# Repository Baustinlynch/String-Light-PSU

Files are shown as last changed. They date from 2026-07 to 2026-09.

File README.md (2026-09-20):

# String-light-controller

an esp-home controller for 4.5V string-lights with PWM dimming and a battery with USB-C recharging.
comes in a version with an 18650 battery holder and a version with a JST PH connector. The JST version is more compact

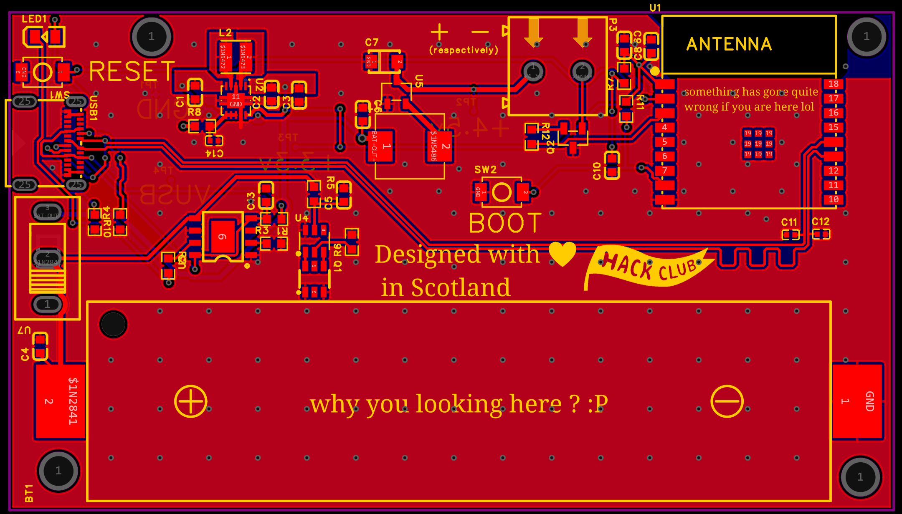
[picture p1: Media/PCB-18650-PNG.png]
an image of the 18650 version of the board's PCB


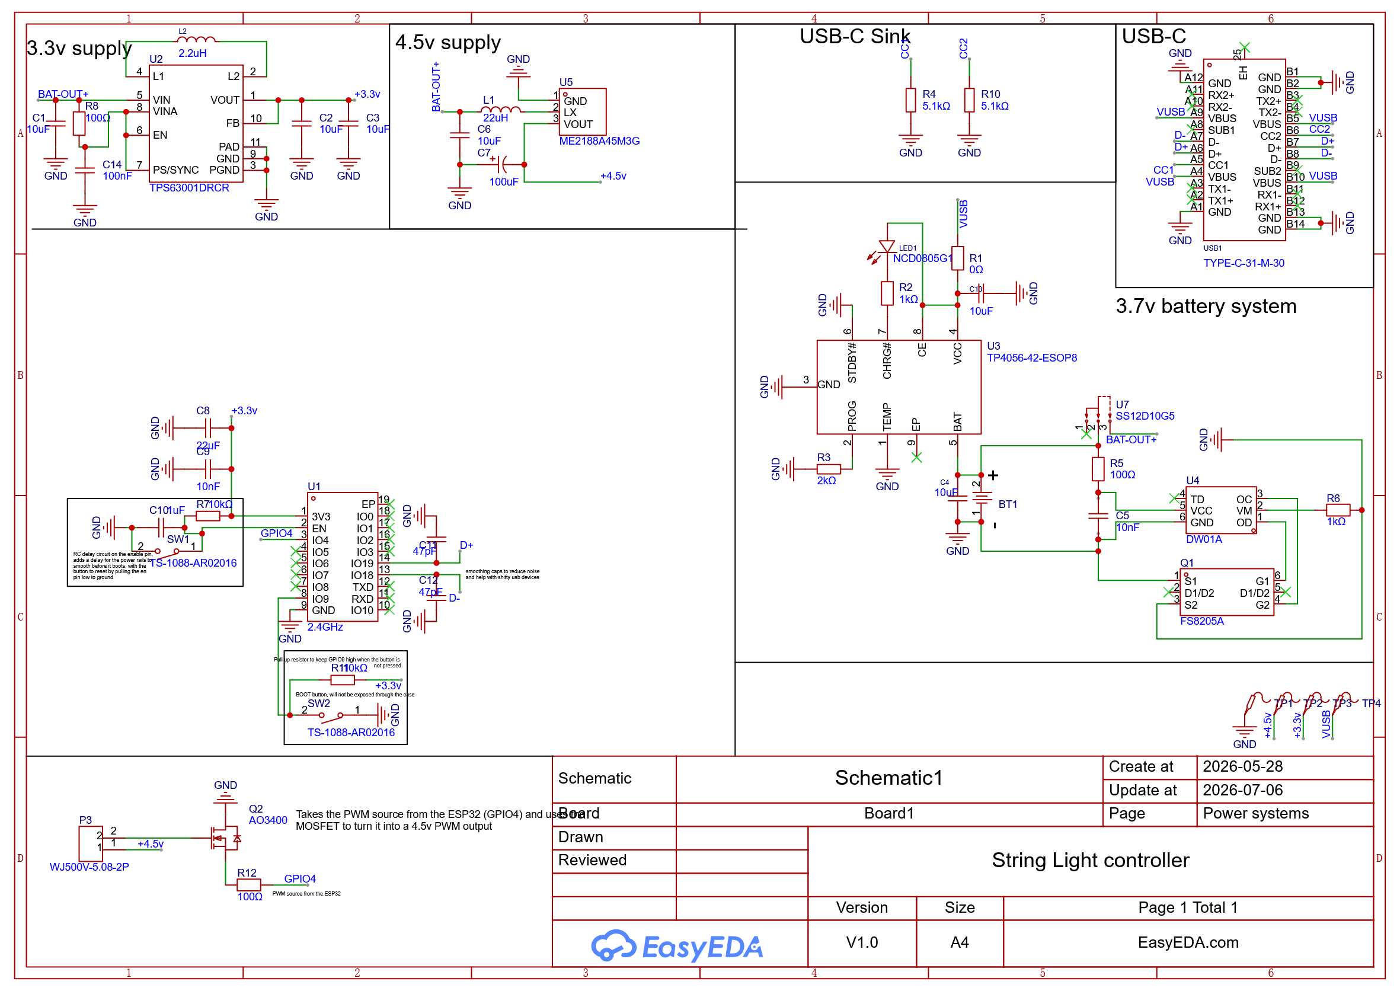
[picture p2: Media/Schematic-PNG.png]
an image of the 18650 version of the board's schematic


## ESP-home implementation

the lights can be controlled using the ESP-home "component" [ESP-32 LEDC output](https://esphome.io/components/output/ledc/).
it allows for the easy creation of a HomeAssistant light entity with dimming based on the PWM output of the esp32 through basic yaml configuration files, that automatically generate the code needed to flash the ESP32, and allow you to flash it through ESP-home web tools.
to define a light using this component, all you **need** to declare in your ESP-home config is the pin on the esp32 (in the case of this board, GPIO4) and the ID that you want the light component to have in HomeAssistant. You can also set the PWM frequency of the pin, the ESP32-C3 which is used in this board only supports 14 bit LEDC timers, as shown on the frequency table on the ESP-home docs page i linked.
Here is an example configuation:

``` yaml
# Example configuration entry
output:
  - platform: ledc
    pin: GPIOXX
    id: gpio_

# Example usage in a light
light:
  - platform: monochromatic
    output: gpio_19
    name: "Kitchen Light"
```

## Operation

The board features an ESP32-C3 to interface with the PWM pin at GPIO4, which is then transformed through the MOSFET (Q2) into a 4.5v PWM signal.
The PWM output can be used to change the brightness of the lights, and can be easily controled through esp-home to turn any 4.5v string lights into smart-lights with HomeAssistant!
String lights that use 3 AA or AAA batteries often operate at 4.5v and should be compatible with this board.
When charging, the red LED (LED1) located next to the usb-c port will be on. it will turn off when full charged

## Assembly
[go to assembly](Assembly.md)

# BATTERY DISCLAIMER !!!
LiPo and LiIon batteries are **pretty dangerous**!! 
I **DO NOT** take responsibility for my battery charging or management circuitry being responsible for your battery being over/under charged and setting on fire.
I trust my circuitry enough to use it in my own home, but you should always look over someone else's circuitry yourself and do your due diligence!
**Use at your own risk!!**

## AI Declaration
Coding and research agents were used in this project, for things like the preparation of the spreadsheets, and for finding blatant errors in my schematics that I may have missed.

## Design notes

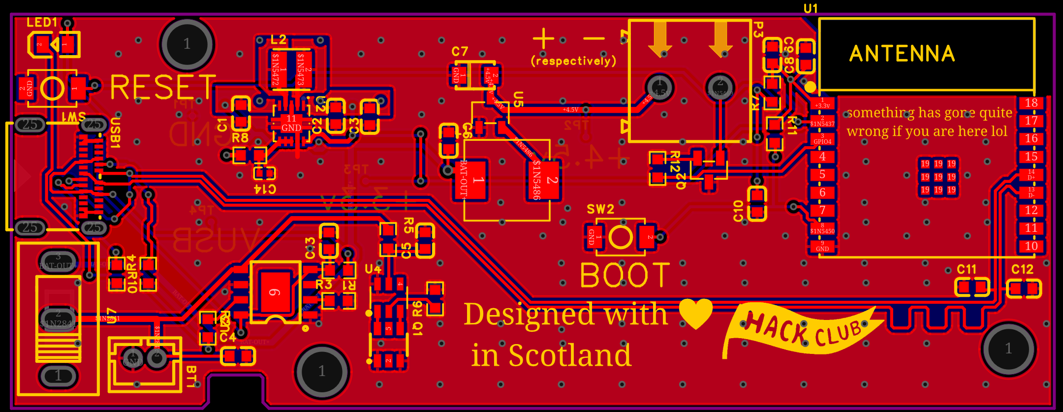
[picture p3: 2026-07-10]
Media/PCB-JST-PNG.png

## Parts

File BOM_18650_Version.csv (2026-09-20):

Part | Quantity | Price | Total
BH-18650-B1BA002 | 1 | 2.0 | 2.0
10uF (C96446) | 4 | 0.0549 | 0.2196
10uF (C96446) | 2 | 0.0549 | 0.1098
10nF (C5137477) | 2 | 0.0072 | 0.0144
100uF (C561794) | 1 | 0.4221 | 0.4221
22uF (C86295) | 1 | 0.0434 | 0.0434
1uF (C15849) | 1 | 0.0153 | 0.0153
47pF (C1671) | 2 | 0.0064 | 0.0128
100nF (C525226) | 1 | 0.0052 | 0.0052
22uH (C128694) | 1 | 0.0846 | 0.0846
2.2uH (C668451) | 1 | 0.1696 | 0.1696
NCD0805G1 | 1 | 2.0 | 2.0
WJ500V-5.08-2P | 1 | 2.0 | 2.0
FS8205A | 1 | 2.0 | 2.0
AO3400 | 1 | 2.0 | 2.0
0Ω (C844915) | 1 | 0.0035 | 0.0035
1kΩ (C2907002) | 2 | 0.0029 | 0.0058
2kΩ (C22975) | 1 | 0.0024 | 0.0024
5.1kΩ (C23186) | 2 | 0.0018 | 0.0036
100Ω (C2906981) | 3 | 0.0021 | 0.0063
10kΩ (C98220) | 2 | 0.0035 | 0.0070
TS-1088-AR02016 | 2 | 2.0 | 4.0
Test-Point | 4 | 2.0 | 8.0
2.4GHz (C2934560) | 1 | 3.3224 | 3.3224
TPS63001DRCR | 1 | 2.0 | 2.0
TP4056-42-ESOP8 | 1 | 2.0 | 2.0
DW01A | 1 | 2.0 | 2.0
ME2188A45M3G | 1 | 2.0 | 2.0
SS12D10G5 | 1 | 2.0 | 2.0
TYPE-C-31-M-30 | 1 | 2.0 | 2.0
3D Printed Case (Base & Top) | 1 | 1.0 | 1.0
M3 x 5mm Threaded Inserts | 4 | 0.2 | 0.8
M3 x 8mm Machine Screws | 4 | 0.1 | 0.4
18650 Battery | 1 | 5.0 | 5.0
GRAND TOTAL | 1 | 73.2 | 73.2

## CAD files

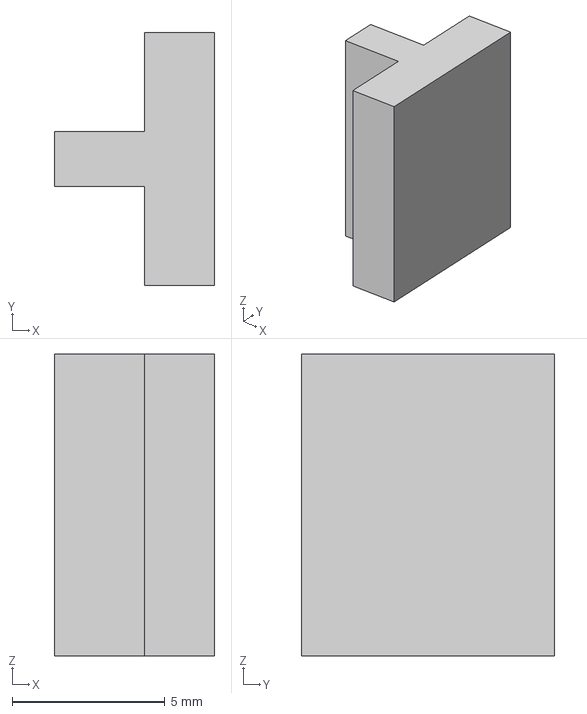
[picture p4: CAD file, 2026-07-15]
CAD/18650/Case Parts/Button Pin.step
5.25 x 8.30 x 9.89 mm

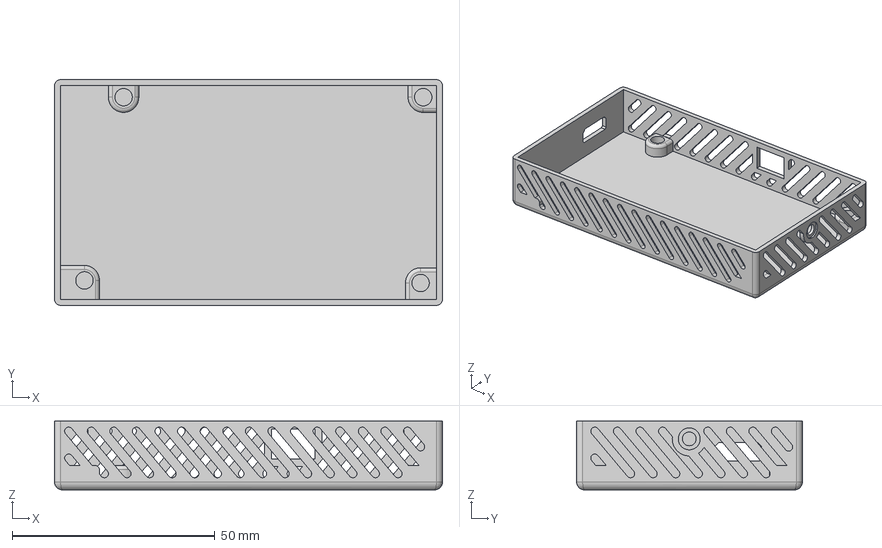
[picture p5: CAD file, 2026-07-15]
CAD/18650/Case Parts/Base.step
95.7 x 55.7 x 17.0 mm

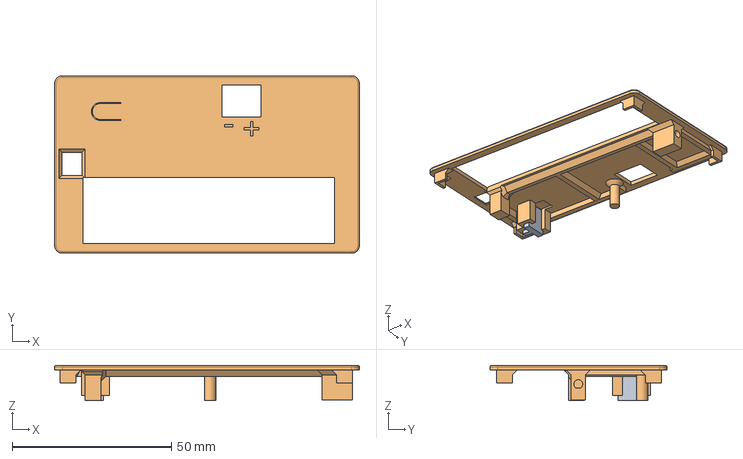
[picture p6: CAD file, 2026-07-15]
CAD/18650/Case Parts/Top.step
95.7 x 55.7 x 11.1 mm

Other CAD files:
CAD/18650/Case Parts/Base.f3d
CAD/18650/Case Parts/Button Pin.f3d
CAD/18650/Case Parts/Top.f3z

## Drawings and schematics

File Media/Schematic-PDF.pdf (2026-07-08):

GND B14 GND B13 RX1+ B12 RX1- B11 VBUS B10 SUB2 B9 D- B8 D+ B7 CC2 B6 VBUS B5 TX2- B4 TX2+ B3 GND B2 GND B1

USB-C Sink | USB-C

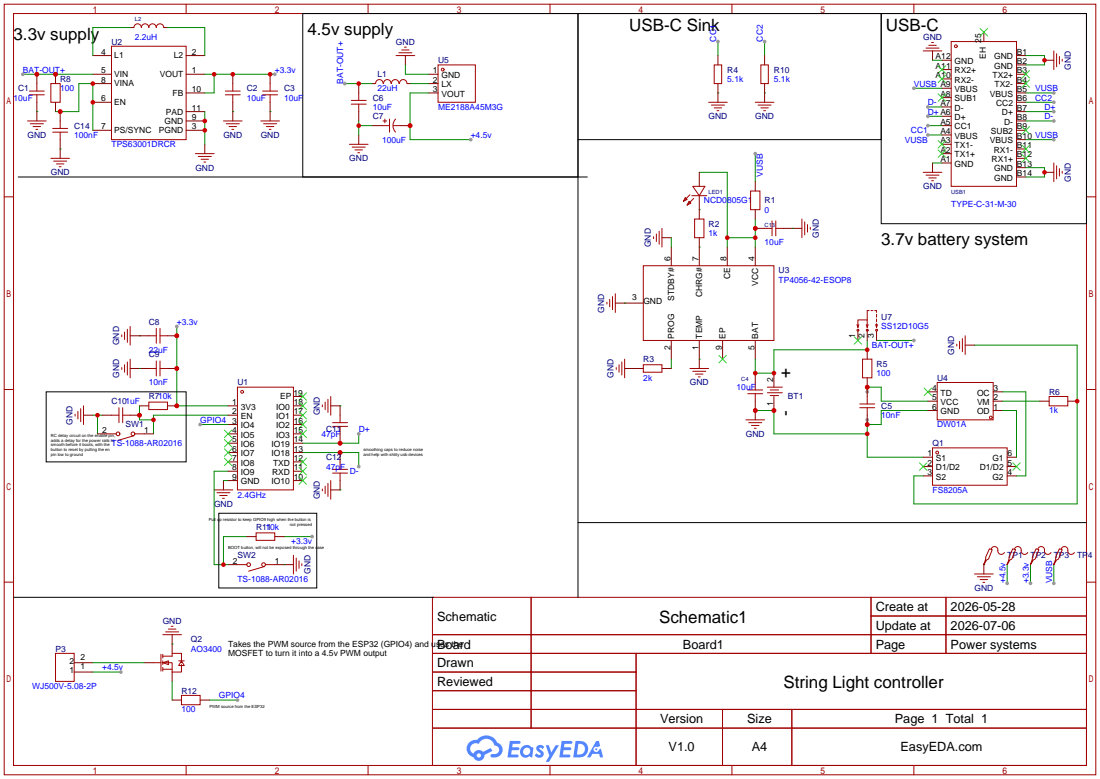
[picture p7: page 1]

RC delay circuit on the enable pin,
adds a delay for the power rails to
smooth before it boots, with the
button to reset by pulling the en
pin low to ground

smoothing caps to reduce noise
and help with shitty usb devices

Pull up resistor to keep GPIO9 high when the button is

BOOT button, will not be exposed through the case

Update at | 2026-07-06

Board | Board1 | Page | Power systems
Drawn | | String Light controller
Reviewed

Takes the PWM source from the ESP32 (GPIO4) and uses the
MOSFET to turn it into a 4.5v PWM output

PWM source from the ESP32

Version | Size | Page 1 Total 1
V1.0 | A4 | EasyEDA.com

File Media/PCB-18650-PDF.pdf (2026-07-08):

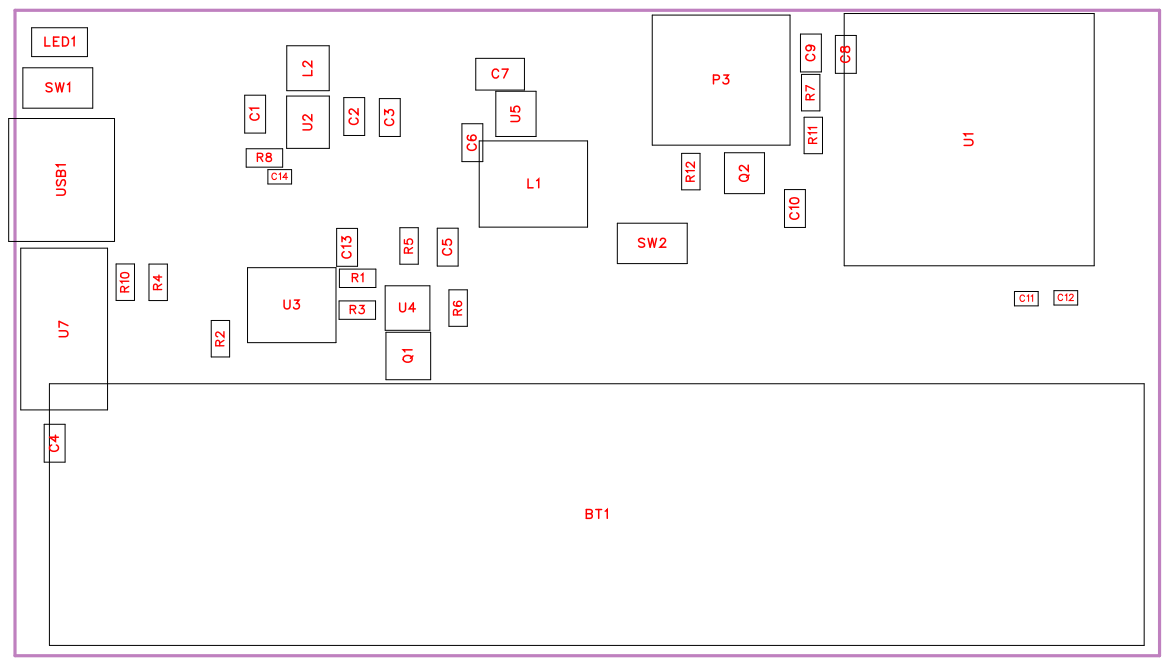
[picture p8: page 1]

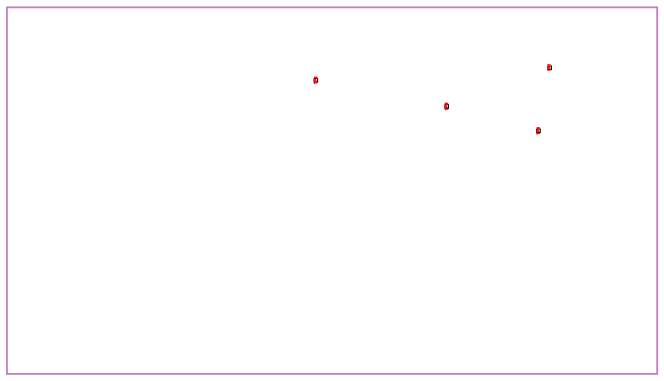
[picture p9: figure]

No. | Quantity | Comment | Designator | Footprint | Value | Manufacturer Part | Manufacturer | Supplier Part | Supplier
1 | 1 | BH-18650-B1 BA002 | BT1 | BATTERY-S MD_18650-1 S-L77.1-W20 .7-1 | | BH-18650-B1 BA002 | MYOUNG( 美 ) 阳 | C2988620 | LCSC
2 | 4 | 10uF | C1,C2,C3,C6 | C0603 | 10uF | CL10B106M Q8NRNC | SAMSUNG( ) 三星 | C3039698 | LCSC
3 | 2 | 10uF | C4,C13 | C0603 | 10uF | CL10A106M A8NRNC | SAMSUNG( ) 三星 | C96446 | LCSC
4 | 2 | 10nF | C5,C9 | C0603 | 10nF | FCC0603B10 3K500CT | FOJAN(富捷 ) | C5137477 | LCSC
5 | 1 | 100uF | C7 | CAP-SMD_L 3.2-W1.6 | 100uF | T520A107M0 06ATE070 | KEMET(基美 ) | C561794 | LCSC
6 | 1 | 22uF | C8 | C0603 | 22uF | CL10A226M P8NUNE | SAMSUNG( 三星 ) | C86295 | LCSC
7 | 1 | 1uF | C10 | C0603 | 1uF | CL10A105KB 8NNNC | SAMSUNG( ) 三星 | C15849 | LCSC
8 | 2 | 47pF | C11,C12 | C0402 | 47pF | CC0402FRN PO9BN470 | YAGEO(国巨 ) | C277503 | LCSC
9 | 1 | 100nF | C14 | C0402 | 100nF | FN15X104K5 00PKG | PSA(信昌电 陶) | C525226 | LCSC
10 | 1 | 22uH | L1 | IND-SMD_L7 .3-W6.6_MH CI06030 | 22uH | SMMS0630-220M | SXN(顺翔诺 ) | C128694 | LCSC
11 | 1 | 2.2uH | L2 | IND-SMD_L3 .0-W3.0_LQ H3NPN2R2N G0L | 2.2uH | LQH3NPN2R 2MMEL | muRata(村田 ) | C668451 | LCSC
12 | 1 | NCD0805G1 | LED1 | LED0805-R-RD | | NCD0805G1 | 国星光电 | C84260 | LCSC
13 | 1 | WJ500V-5.08 -2P | P3 | CONN-TH_2 P-P5.00_WJ 500V-5.08-2 P | | WJ500V-5.08 -2P | KANGNEX( 康奈克斯电气 ) | C8465 | LCSC
14 | 1 | FS8205A | Q1 | SOT-23-6_L2 .9-W1.6-P0.9 5-LS2.8-BR | | FS8205A | TECH PUBLI C(台舟 ) | C2830320 | LCSC
15 | 1 | AO3400 | Q2 | SOT-23-3_L2 .9-W1.3-P0.9 5-LS2.4-BR | | AO3400 | ElecSuper( 静 芯 ) | C5224189 | LCSC
16 | 1 | 0 | R1 | R0603 | 0 | CRCW06030 000Z0EA | VISHAY(威世 ) | C844915 | LCSC
17 | 2 | 1k | R2,R6 | R0603 | 1k | FRC0603F10 01TS | FOJAN(富捷 ) | C2907002 | LCSC
18 | 1 | 2k | R3 | R0603 | 2k | 0603WAF20 01T5E | UNI-ROYAL( ) 厚声 | C22975 | LCSC
19 | 2 | 5.1k | R4,R10 | R0603 | 5.1k | 0603WAF51 01T5E | UNI-ROYAL( 厚声 ) | C23186 | LCSC

20 | 3 | 100 | R5,R8,R12 | R0603 | 100 | FRC0603F10 00TS | FOJAN(富捷 ) | C2906981 | LCSC
21 | 2 | 10k | R7,R11 | R0603 | 10k | RC0603FR-0 710KL | YAGEO(国巨 ) | C98220 | LCSC
22 | 2 | TS-1088-AR 02016 | SW1,SW2 | SW-SMD_L3 .9-W3.0-P4.4 5 | | TS-1088-AR 02016 | XUNPU(讯普 ) | C720477 | LCSC
23 | 4 | Test-Point | TP1,TP2,TP3,TP4 | Test-Point-0. 5mm
24 | 1 | 2.4GHz | U1 | BULETM-SM D_ESPRESS IF_ESP32-C 3-WROOM-0 2-N4-4MB | 2.4GHz | ESP32-C3-W ROOM-02-N 4 | ESPRESSIF( 乐鑫 ) | C2934560 | LCSC
25 | 1 | TPS63001D RCR | U2 | VSON-10_L3 .0-W3.0-P0.5 0-TL-EP_TP S62410DRC R | | TPS63001D RCR | TI(德州仪器 ) | C28060 | LCSC
26 | 1 | TP4056-42-E SOP8 | U3 | ESOP-8_L4. 9-W3.9-P1.2 7-LS6.0-BL-E P | | TP4056-42-E SOP8 | TOPPOWER (南京拓微) | C16581 | LCSC
27 | 1 | DW01A | U4 | SOT-23-6_L2 .9-W1.6-P0.9 5-LS2.8-BL | | DW01A | PUOLOP( 迪 ) 浦 | C351410 | LCSC
28 | 1 | ME2188A45 M3G | U5 | SOT-23-3_L2 .9-W1.6-P1.9 0-LS2.8-BR | | ME2188A45 M3G | MICRONE( 南 ) 京微盟 | C2835781 | LCSC
29 | 1 | SS12D10G5 | U7 | SW-TH_SHO U-HAN_SS1 2D10G4 | | SS12D10G5 | SHOU HAN(首韩 ) | C7431054 | LCSC
30 | 1 | TYPE-C-31-M-30 | USB1 | USB-C-SMD _TYPE-C-31-M-30 | | TYPE-C-31-M-30 | 韩国韩荣 | C2689970 | LCSC

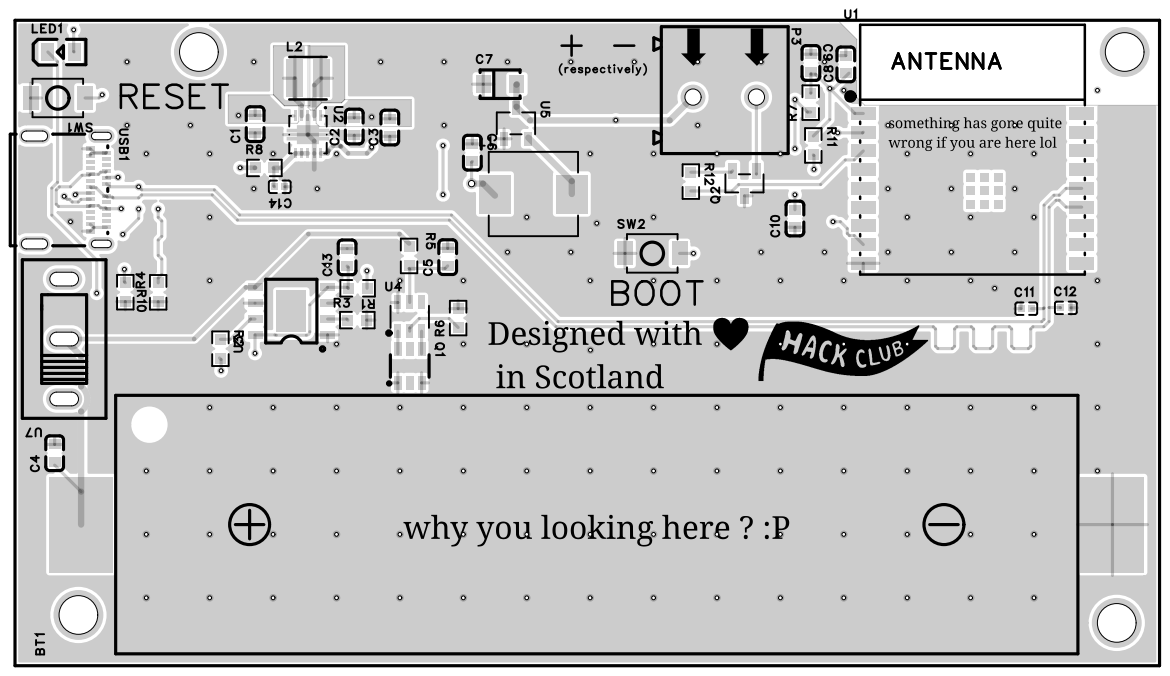
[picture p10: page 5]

LED1 | ANTENNA

something has gone quite
wrong if you are here lol

why you looking here ? :P

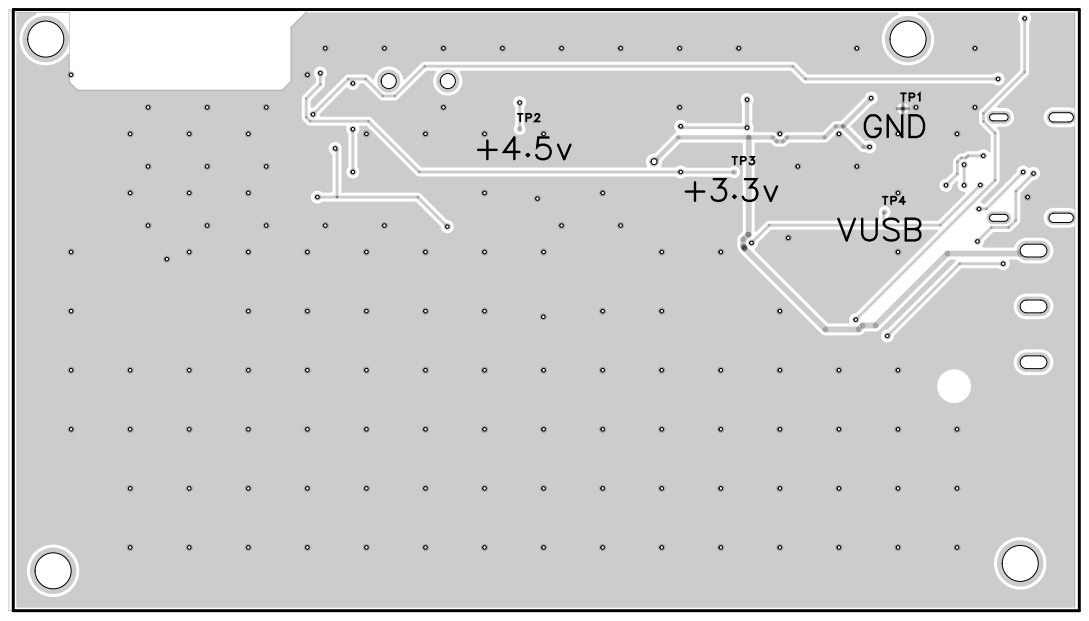
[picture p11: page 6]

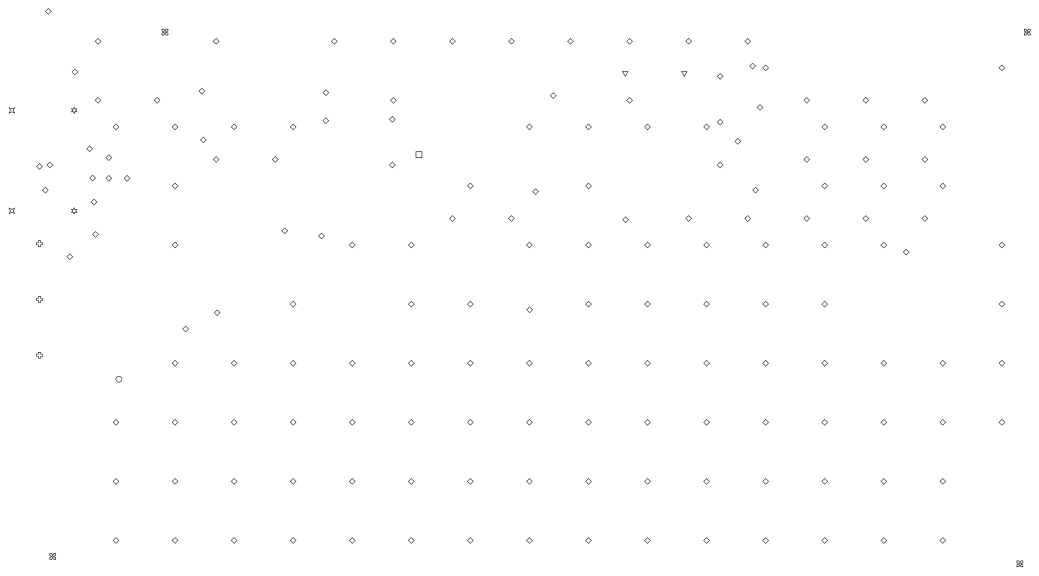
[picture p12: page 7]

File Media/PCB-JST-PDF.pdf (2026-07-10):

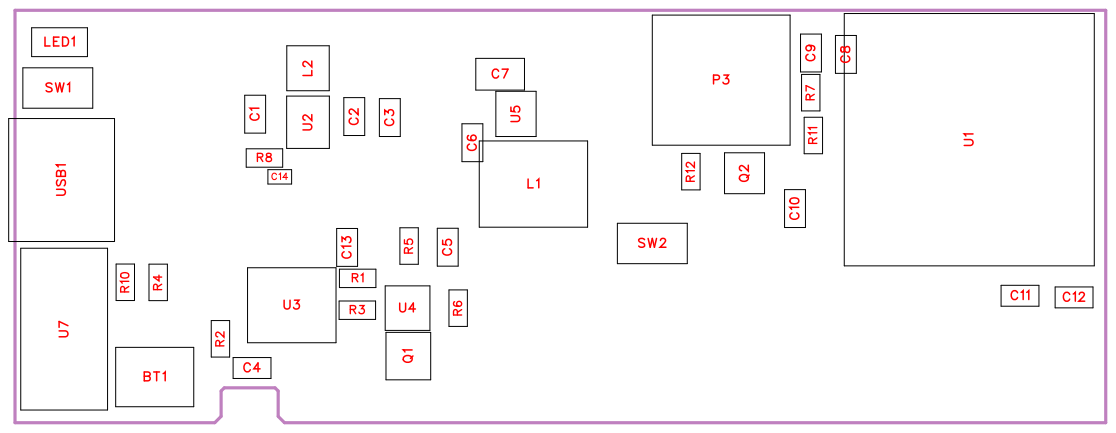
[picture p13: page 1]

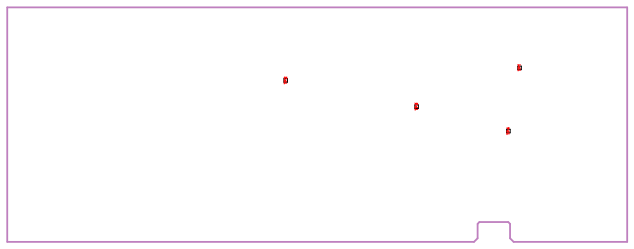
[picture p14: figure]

No. | Quantity | Comment | Designator | Footprint | Value | Manufacturer Part | Manufacturer | Supplier Part | Supplier
1 | 1 | B2B-PH-K-S( LF)(SN) | BT1 | CONN-TH_B 2B-PH-K-S | | B2B-PH-K-S( LF)(SN) | JST | C131337 | LCSC
2 | 4 | 10uF | C1,C2,C3,C6 | C0603 | 10uF | CL10B106M Q8NRNC | SAMSUNG( ) 三星 | C3039698 | LCSC
3 | 2 | 10uF | C4,C13 | C0603 | 10uF | CL10A106M A8NRNC | SAMSUNG( 三星 ) | C96446 | LCSC
4 | 2 | 10nF | C5,C9 | C0603 | 10nF | FCC0603B10 3K500CT | FOJAN(富捷 ) | C5137477 | LCSC
5 | 1 | 100uF | C7 | CAP-SMD_L 3.2-W1.6 | 100uF | T520A107M0 06ATE070 | KEMET(基美 ) | C561794 | LCSC
6 | 1 | 22uF | C8 | C0603 | 22uF | CL10A226M P8NUNE | SAMSUNG( ) 三星 | C86295 | LCSC
7 | 1 | 1uF | C10 | C0603 | 1uF | CL10A105KB 8NNNC | SAMSUNG( ) 三星 | C15849 | LCSC
8 | 2 | 47pF | C11,C12 | C0603 | 47pF | CL10C470JB 8NNNC | SAMSUNG( 三星 ) | C1671 | LCSC
9 | 1 | 100nF | C14 | C0402 | 100nF | FN15X104K5 00PKG | PSA(信昌电 陶) | C525226 | LCSC
10 | 1 | 22uH | L1 | IND-SMD_L7 .3-W6.6_MH CI06030 | 22uH | SMMS0630-220M | SXN(顺翔诺 ) | C128694 | LCSC
11 | 1 | 2.2uH | L2 | IND-SMD_L3 .0-W3.0_LQ H3NPN2R2N G0L | 2.2uH | LQH3NPN2R 2MMEL | muRata(村田 ) | C668451 | LCSC
12 | 1 | NCD0805G1 | LED1 | LED0805-R-RD | | NCD0805G1 | 国星光电 | C84260 | LCSC
13 | 1 | WJ500V-5.08 -2P | P3 | CONN-TH_2 P-P5.00_WJ 500V-5.08-2 P | | WJ500V-5.08 -2P | KANGNEX( 康奈克斯电气 ) | C8465 | LCSC
14 | 1 | FS8205A | Q1 | SOT-23-6_L2 .9-W1.6-P0.9 5-LS2.8-BR | | FS8205A | TECH PUBLI C(台舟 ) | C2830320 | LCSC
15 | 1 | AO3400 | Q2 | SOT-23-3_L2 .9-W1.3-P0.9 5-LS2.4-BR | | AO3400 | ElecSuper( 静 ) 芯 | C5224189 | LCSC
16 | 1 | 0 | R1 | R0603 | 0 | CRCW06030 000Z0EA | VISHAY(威世 ) | C844915 | LCSC
17 | 2 | 1k | R2,R6 | R0603 | 1k | FRC0603F10 01TS | FOJAN(富捷 ) | C2907002 | LCSC
18 | 1 | 2k | R3 | R0603 | 2k | 0603WAF20 01T5E | UNI-ROYAL( 厚声 ) | C22975 | LCSC
19 | 2 | 5.1k | R4,R10 | R0603 | 5.1k | 0603WAF51 01T5E | UNI-ROYAL( 厚声 ) | C23186 | LCSC
20 | 3 | 100 | R5,R8,R12 | R0603 | 100 | FRC0603F10 00TS | FOJAN(富捷 ) | C2906981 | LCSC

21 | 2 | 10k | R7,R11 | R0603 | 10k | RC0603FR-0 710KL | YAGEO(国巨 ) | C98220 | LCSC
22 | 2 | TS-1088-AR 02016 | SW1,SW2 | SW-SMD_L3 .9-W3.0-P4.4 5 | | TS-1088-AR 02016 | XUNPU(讯普 ) | C720477 | LCSC
23 | 4 | Test-Point | TP1,TP2,TP3,TP4 | Test-Point-0. 5mm
24 | 1 | 2.4GHz | U1 | BULETM-SM D_ESPRESS IF_ESP32-C 3-WROOM-0 2-N4-4MB | 2.4GHz | ESP32-C3-W ROOM-02-N 4 | ESPRESSIF( ) 乐鑫 | C2934560 | LCSC
25 | 1 | TPS63001D RCR | U2 | VSON-10_L3 .0-W3.0-P0.5 0-TL-EP_TP S62410DRC R | | TPS63001D RCR | TI(德州仪器 ) | C28060 | LCSC
26 | 1 | TP4056-42-E SOP8 | U3 | ESOP-8_L4. 9-W3.9-P1.2 7-LS6.0-BL-E P | | TP4056-42-E SOP8 | TOPPOWER (南京拓微) | C16581 | LCSC
27 | 1 | DW01A | U4 | SOT-23-6_L2 .9-W1.6-P0.9 5-LS2.8-BL | | DW01A | PUOLOP( 迪 浦 ) | C351410 | LCSC
28 | 1 | ME2188A45 M3G | U5 | SOT-23-3_L2 .9-W1.6-P1.9 0-LS2.8-BR | | ME2188A45 M3G | MICRONE( 南 ) 京微盟 | C2835781 | LCSC
29 | 1 | SS12D10G5 | U7 | SW-TH_SHO U-HAN_SS1 2D10G4 | | SS12D10G5 | SHOU HAN(首韩 ) | C7431054 | LCSC
30 | 1 | TYPE-C-31-M-30 | USB1 | USB-C-SMD _TYPE-C-31-M-30 | | TYPE-C-31-M-30 | 韩国韩荣 | C2689970 | LCSC

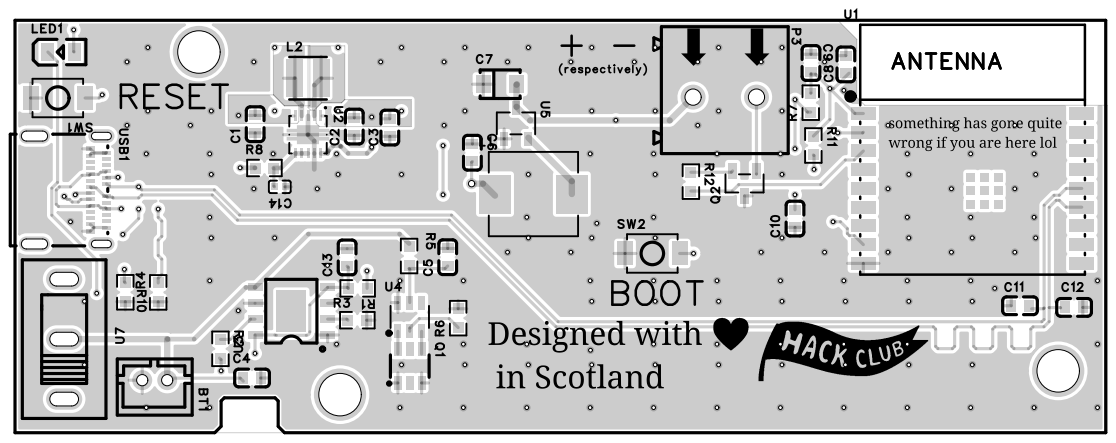
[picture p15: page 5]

LED1 | ANTENNA

something has gone quite
wrong if you are here lol

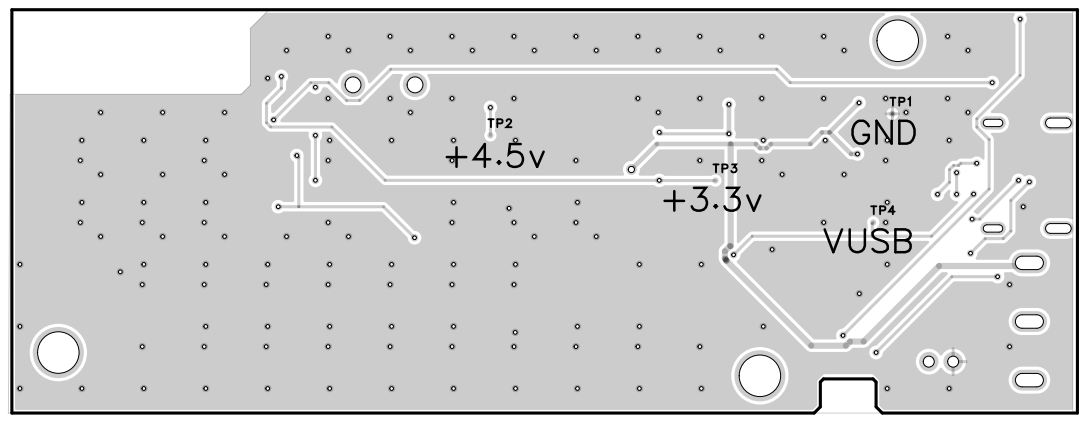
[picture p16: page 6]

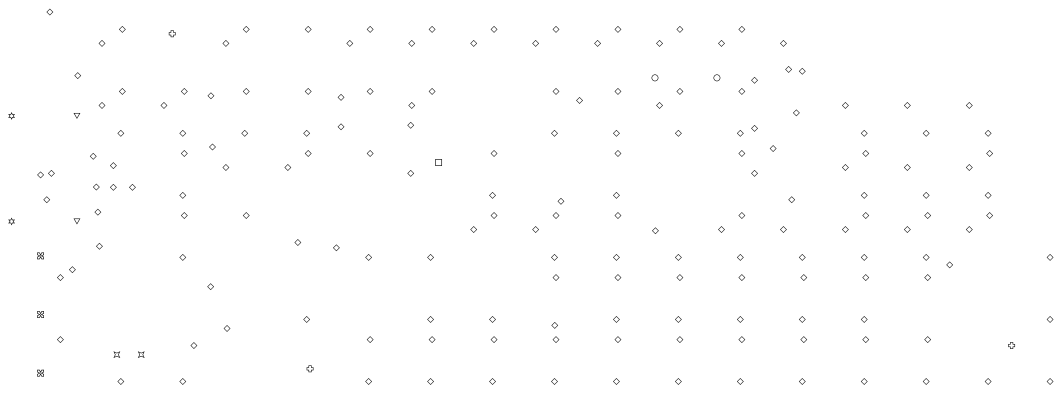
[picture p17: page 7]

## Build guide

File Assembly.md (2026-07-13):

# Assembly

All PCB parts can be assembled by JLCPCB PCBA, but I have also selected parts that are relatively easy to solder by hand using a hotplate and soldering iron.

## 18650 version

### Parts

- One fully assembled board
- One 18650 battery
- 3D printed case parts
  - These should be fine printed in PLA, but a higher-temperature filament may be better as some switching regulators can produce more heat that PLA may not handle.
- 4 M3 threaded inserts (full dimensions will be picked later; I haven't finished modeling it yet)
- 4 M3 by 8mm machine screws

### Tools

- lil screwdriver for the wire terminal
- flush cutters and wire strippers for separating out the wires for the string lights from the battery holder
- if you want, a command strip for wall mounting
- m3 heat-set insert tool (e.g. something like [this](https://cnckitchen.store/products/c210-installation-tips-set))

### Assembling

1. insert the threaded inserts into the holes on the bottom of the base piece of the enclosure, using a soldering iron with an insert tool or any other way of putting it in.
2. place the PCB into the base of the enclosure and connect it to the base by using the M3 bolts and screwing them through the holes in the PCB into the threaded inserts in the base
3. insert the 18650 battery into the battery carrier on the board
4. place the reset button pin into the top plate of the enclosure
5. attach the top of the enclosure to the base, then attach it via the (not been fully designed yet so i like dont know how it will be attached)
6. Charge and program the board

   1. plug the board in via usb-c to any PD or 5v supply
   2. once charged, program the board with your code using the ESPHome web flasher

7. cut the wires of the string lights that connect to the battery holder
8. strip the wires of the string lights, by about 1 or 2 mm
9. insert the ends of the wires into the wire terminals and use your lil screw driver to tighten them down
  - make sure that you get the polarity of the wires correct, according to the embossed polarity symbols on the top of the enclosure

## JST version

### Parts

- One fully assembled board
- One jst battery
- 3D printed case parts
  - These should be fine printed in PLA, but a higher-temperature filament may be better as some switching regulators can produce more heat that PLA may not handle.
- 3 M3 threaded inserts (full dimensions will be picked later; I haven't finished modeling it yet)
- 3 M3 by 8 mm machine screws  
- a non-thermal, removable adhesive for mounting the battery in the enclosure (not strictly required)

### Tools

- lil screwdriver for the wire terminal
- flush cutters and wire strippers for seperating out the wires for the string lights from the battery holder
- if you want, a command strip for wall mounting

### Assembling

1. insert the 3 threaded inserts into the holes in the base of the enclosure
2. place the battery into the base of the enclosure and, if you want, use a light adhesive to attach it into its place.
3. place the PCB into the base of the enclosure
4. place the top of the enclosure onto the base, pinning the PCB between the 2 parts
5. use the M3 machine screws to attach the base and top of the enclosure together
6. Charge and program the board
  1. plug the board in via usb-c to any PD or 5v supply
  2. once charged, program the board with your code using the ESPHome web flasher 
7. cut the wires of the string lights from the battery holder
8. strip back the insulation on the battery holder by about 1-2mm
9. insert the wires from the string light into the wire terminals and screw them into place
  - make sure that you get the polarity of the wires right !!

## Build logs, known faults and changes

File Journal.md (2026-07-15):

# Journal

## 8/5/26

- Found the ESP-32 MCU i want to use ([ESPRESSIF ESP32-S3-WROOM-1-N8](https://www.lcsc.com/product-detail/C2913198.html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))
- [Found 18650 battery mount tray](https://www.lcsc.com/product-detail/C2988620.html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)
- Got the [USB-C Port](https://www.lcsc.com/product-detail/C2689970.html?s_z=n_q_C2689970&globalKeyword=C2689970)
- Got the [PD sink from a previous project](https://www.lcsc.com/product-detail/C22373734.html?s_z=n_q_C22373734&globalKeyword=C22373734)
- Find the Battery charger ic i want to use ([the TP4056](https://www.lcsc.com/product-detail/C16581.html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))
  - Spent a while setting the battery charging circut up

- Started the Layout and routing on the PCB

<https://lapse.hackclub.com/timelapse/oYXOqTZ7uB9a>

## 9/5/26

- did a bit more routing and declared some parts

## 27/5/26

- found the BMS ic i want to use [on LCSC](https://www.lcsc.com/product-detail/C351410.html)
- also found a better data sheet from [Digikey](https://www.digikey.co.uk/en/products/detail/shenzhen-slkormicro-semicon-co-ltd/DW01A/28143000) because the one on LCSC was a bit too vague
- finished the 3.7v battery system schematic
- re-routed the entire board so far, as it is routed very bad

## 28/5/26

- made 2 pages in the schematic for the power systems and for the MCU and 4.5v switching for the output to the string lights

## 6/6/26

Fun date

- Found the screw terminal i want to use to connect the 4.5v output to the string light leads
- looked into the 3.7v to 4.5v converter i want to use

## 01/07/26

- finished the 4.5v boost circut

## 02/07/26

- re-did the 4.5v boost circut but remembered to save it this time lol
- added test-points for the +4.5v and +3.3v rails so that i can test that the converters are working correctly
- added a test point for the VUSB net so that i can check that the correct voltage (5v) is being negotiated by the usb-c sink
- added a power switch to the output from the BMS
- added reset button
- applied parts to some of the passives i had placed over time

## 03/07/26

- added smoothing caps to the usb data lines
- connected the enable pin of the TPS61254YFFR(4.5v boost ic) to GPIO-1 on the esp32 so that i can control it from EspHome by driving the pin high
- put no-connect flags on all the unused pins
- started to layout the PCB for the (hopefully final time) whilst doing so, checking over the schematic for every part

## 04/07/26

- finished layout of the PCB
- added a little silkscreen message :)
- changed the size of the vias on the ground pin of the esp32-s3 as they were too small for JLCPCB
- made sure that the ground plane was not under the antenna of the esp32 so that the performance of wifi is less affected
- checked ordering through JLCPCB to make sure that they can make it all
- found that PCBA is super expensive, looking at soldering the parts myself
- finding replacements for some parts because they are out of stock

## 05/07/26

all of the changes i am making today are as a result of asking for someone to look over my schematic on ([#electronics](https://hackclub.slack.com/archives/C056AMWSFKJ/p1783166697054009)) in Slack and getting feedback :)
today i am going to:

- [X] Remove the PD sink and replace it with 2 5.k resistors to reduce cost. As i am getting 5v from the usb-c supply, i don't need to use a sink because it does not require proper PD negotiation, and it can request 5v from any usb-c source by just putting a 5.1k resistor to ground on each cc pin
  - removed the sink and placed the resistors
- [X] replace the esp32-s3 with and esp32-c3 to reduce cost, as the s3 is more powerful than i need for this application
  - change up the boot button so that it holds GPIO9 high when not pressed
  - connect up all the other parts
- [X] use the PWM pins on the c3 to allow for dimming for the lights
  - found a MOSFET to take the 3.3v PWM output from the esp32 and turn it into a 4.5v PWM output for the load
  - set up the MOSFET to transform the PWM signal from the ESP32 to a 4.5v PWM output for the lights
- finished the layout of the PCB
- removed the 0 ohm resistors as they are unnecessary for the length of my usb data lines
- 4 m3 mounting holes

## 06/07/26

- changed my 3.3v source, the one i was using, LCSC dont have carry anymore
  - im now going to be using the TI TPS63001DRCR
- found the inductor i want to be using, i got it from the recommended parts list from TI.
  - placed all the resistors and caps needed
  - finished the layout for the 3.3v source
- checked ordering at JLCPCB to make sure there arent any problems
  - replace R2 and R6 as the ones i had selected are now out of stock at LCSC
- whilst i was checking the JLCPCB ordering, i found that the 4.5v boost ic i was using is not compatible with the economic PCBA with JLCPCB, and can only be done with the standard PCBA, which costs around $145. due to the package size i cannot solder it myself, so i must find an alternative ic
  - found the ME2188A45, it is a working alternative for the TPS61254YFFR
  - placed and assembled it on the schematic
  - finished the layout on the PCB, and beefed up some of the traces that will be taking high current
  
## 08/07/26

- started modeling the base of the enclosure
  - created the basic outside shape
  - added the bases for the threaded inserts to hold in the PCB

## 09/07/26

- added vents to one side of the base of the enclosure
- added vents to the opposite side to the usb-c port
- sliced the base of the enclosure to get a better feel for how it will print, i think i need to make the walls between the vents a bit bigger, it looks like it will be a bit too fragile
  - made the gaps between each of the vents bigger
- finished up the base (for now)
  - except i still need to find some threaded inserts for the bolts from the PCB to go into, and need to figure out how i am going to attach the top and bottom pieces of the enclosure together
- printed the base as it is now so that i can make sure that the bottom and top fit together properly
- the base finished printing, i think that the vents are still too a bit weak, i need to make the gaps between the holes bigger.

## 10/07/26

- [X] i need to make the caps on the usb data lines bigger, as they are too small to solder by hand rn
- [X] i need to make the mounting holes in the PCB bigger as they are a bit too small for the M3 bolts

- I made the non-18650/JST version of the board
  - i plan on using [this battery](https://thepihut.com/products/2000mah-3-7v-lipo-battery) for my version of the enclosure
  - i am going to use [this JST connector](https://www.lcsc.com/product-detail/C131337.html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)
  - did the layout for the JST board, and made it more compact than the 18650, as is the benefit of the non-18650 board
  - added a cutout to the board, next to the battery connector, to allow the wires to pass to the bottom of the board.
- started puting all the files into the Github repo

## 13/07/26

- [X] i need to make the vents on the base of the enclosure smaller, they feel a bit too weak
- [X] i need to make the holes for the heated inserts bigger in the base of the 18650 board as i haven't made them the right size for the insert, i have just made them the size of the bolt
  - made the holes in the base 4.2 mm, as my threaded inserts have an outer diameter of 4.8mm. I got the sizing and offsets from [this](https://www.cnckitchen.com/blog/tipps-amp-tricks-fr-gewindeeinstze-im-3d-druck-3awey) article
  - since i made the holes bigger, i also had to make the outer diameter of the parts that hold the inserts bigger
  - i have started a print of the base of the enclosure, so that i can feel how effective my changes have been

- found the size of heat-set insert and machine screws i want to use, i am using M3x8 machine screws ([these](https://uk.store.bambulab.com/products/m3-socket-head-cap-machine-screws-shcs-1?id=41622217621564) ones from Bambu lab) and M3 heat-set inserts with an external diameter of 4.8mm and a height of 3.8mm, as those are suitable and i have them on hand

### 18650 version

- finishing up the enclosure for the 18650 version
  - added a hole in the side of the base so that i can have an m3 machine screw go into the side of one of the support pillars on the top of the enclosure, to attach the top to the bottom of the enclosure
  - sketch 5 is fucked, i cant select any of the profiles to extrude them, im just going to fully remake the sketch at this point
  - fixed sketch 5
  - printing out both of the parts of the enclosure to check the fit
    - i think that the top of the enclosure can be made a bit thinner overall, as it is very bulky
    - the holes for the threaded inserts are a bit small so i am going to make them bigger
    - the hole for the screw that holds in the top of the enclosure is a bit too shallow, so i will make it deeper
  - printing out another copy
    - [] i need to move one of the ribs on the underside of the top of the enclosure away from the hole
    - [] remove the chamfer on the pin with the screw, as it interferes with it being able to fit properly
    - [] add more ribs to the underside of the top of the enclosure as it still a bit too flexible
    - [] make the pin with the screw on it a bit shorter, as it is too long
    - [] add a fillet's to the top of the enclosure

### JST version

- started working on the base of the JST Version enclosure
  - the board is not that big, so the battery that i was planning on using is too big to fit underneath it, and the JST version is supposed to be the small one, so i am going to switch to [this one](https://thepihut.com/products/500mah-3-7v-lipo-battery)
  - since i have changed the battery, i can make the standoffs on for the board shorter, from 8mm to 5mm
  - the walls need to be reasonably thick because of the space necessary for the screws to fit in, so i am minimizing the wall thickness by not having the wall thickness be even everywhere
  - i am carving a kind of alcove into the side of the base of the enclosure, as the battery is in the way of the pins of the screw terminal
  
## 14/07/26

- [X] move the rib on the underside of the top of the enclosure away from the hole
- [X] remove the chamfer on the pin with the screw, as it interferes with it being able to fit properly
- [X] add more ribs to the underside of the top of the enclosure as it is still a bit too flexible
- [X] make the pin with the screw in it shorter, as it is too long
- [X] add a fillet to the top of the enclosure

### 18650 version

- i reshaped the hole for the screw on the top of the enclosure, as it is kinda deformed when it was printed so i am going to flatten the top a bit so that it prints better. I also made the hole smaller so that i has more grip
- added the pass-through for the reset button on the 18650 version of the board
  - cut the hole into the top of the enclosure and added the container/rails for the button to go along
  - modeled the stick thing so that the button can be pushed from outside the enclosure and constrained it into the assembly
- printing out the 18650 version so that i can see how it all fits together
  - the hole for the button is way to small
  - the pass-through pin is too tight in its tracks
- Moved the reset button because the place that i had it is too inaccessible
  - i moved it on the PCB
    - re-uploaded all the files to GitHub#
    - changed the model in fusion
  - re-modeling the button because the way i had it doesnt really work
    - added a flexible interface into the top of the enclosure, to stop the pin from being able to fall out of the top of the enclosure
    - printed out the top of the case and the new button
      - the pin for the button was too short, made it a bit longer
    - printed it again
      - made the pin a bit longer, and the flexible cover for the pin needs to be thicker, it seems that even from this basic amount of use it was already getting weak

### JST version

- moved the screw terminals on the JST version closer to the edge as the through-hole pins were interfering with the space for the battery
  - re upload all of the files for the JST version on GitHub
  - changed the model in Fusion
- added tabs to hold the battery in place in the JST version
- moved the reset button because, in the place that i had it is too inaccessible
  - moved it on the pcb
  - re-uploaded all of the files to GitHub
  - changed the model in fusion
- put the hole in for the top of the enclosure for the screw terminals
- put a hole in the side of the enclosure for the screw terminals

## 15/07/26

### JST version

- added the standoffs for the threaded inserts, i still need to make some spaces in the edge of the base of the enclosure for them as they dont have the clearance to fit in properly
- made room in the sides of the base of the enclosure for the standoffs to fit
- added the flexible cover for the button to the JST version
- modeled the button extender pin for the JST version
- assembled the top of the JST enclosure
- printed out all the parts to test the fit
  - the wall where i made the cutout for the battery is too thin
  - the button pin is too tight in its tracks
- made the wall 0.5mm thicker
- changed the size of the top of the enclosure to make sure its the same as the base
- made the button pin smaller
- printed out all the changed parts to check the fit
  - 

### 18650 version 

- printed it again to see if the the thicker flexible cover is still working
  - it still works great, feels more suitably sturdy now though
- Uploaded all the CAD files to GitHub

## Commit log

2026-07-03 Update journal with recent circuit developments and enhancements
2026-07-03 Add updates for 03/07/26: added smoothing caps, connected TPS61254YFFR enable pin, added no-connect flags, and revised PCB layout
2026-07-04 Update journal with recent PCB layout progress and enhancements
2026-07-05 Update journal with recent changes: corrected casing in data sheet reference, removed PD sink, replaced ESP32-S3 with ESP32-C3, and implemented PWM control for dimming lights.
2026-07-05 Update journal: finished PCB layout, removed unnecessary 0 ohm resistors, and added 4 M3 mounting holes
2026-07-08 Update README.md with detailed assembly instructions and remove todo.md
2026-07-08 Refactor assembly documentation: move detailed assembly instructions to a new Assembly.md file
2026-07-10 Fix assembly instructions and update README for HomeAssistant compatibility
2026-07-10 Add tools section and improve assembly instructions in README
2026-07-10 update journal and upload STEP files, gerber files, BOM list, EASYEDA project files, Pick and Place files, and PDF's and Images of the boards and schematics. Make folders for PCB files, and for CAD f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
    [BOM_Board-PCB-18650.xlsx, BOM_Board-PCB-JST.xlsx, PickAndPlace_PCB_18650.xlsx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]
2026-07-10 fix formatting in README.md for assembly link
2026-07-10 add battery disclamer to the readme
2026-07-10 add a full stop in the battery disclamer
2026-07-11 update assembly instructions and add charging LED information to README
2026-07-13 Update Assembly.md and Journal.md for clarity and formatting improvements
2026-07-14 Replace files as i moved the screw terminal on the JST version of the PCB
    [PickAndPlace_PCB_JST.xlsx]
2026-07-14 moved the reset button on the 18650 version of the board so i needed to re-upload all of the files to GitHub
    [PickAndPlace_PCB_18650.xlsx]
2026-07-14 reuploaded all of the files for the JST version as i moved the reset button + Update Journal.md
    [PickAndPlace_PCB_JST.xlsx]
2026-07-14 Update Journal.md with changes to reset button location and enclosure modifications
2026-07-15 upload cad files for the 18650 version and update Journal.md
    [Base.f3d, Base.step, Button Pin.f3d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]
2026-09-20 added BOM for both versions
    [BOM_18650_Version.csv, BOM_JST_Version.csv]
2026-09-20 Add BOM files for 18650 and JST versions
2026-09-20 remove text versions of the BOM
